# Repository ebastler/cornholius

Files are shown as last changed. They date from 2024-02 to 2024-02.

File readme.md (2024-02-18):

# Cornholius Keyboard

Cornholius is, first and foremost, a Bluetooth Low Energy capable replacement PCB for the [Foostan Cornelius](https://github.com/foostan/corneliuskbd). Key and connector positions as well as PCB outline and plate were derived from the original Cornelius repository, but altered to fit the scope of this project - Thank you for open sourcing these files! In accordance with the license chosen by foostan, this project was published under the same license: <a href="http://creativecommons.org/licenses/by-nc-sa/4.0/?ref=chooser-v1" target="_blank" rel="license noopener noreferrer" style="display:inline-block;">CC BY-NC-SA 4.0</a>.

Parts of this project:
* [PCB](./hotswap_ble/) [100%]
* [Plate](./plate_ble/) [100%]
* 3D printable cornelius/cornholius PCB compatible case [WIP]

## Cornholius PCB
The PCB is designed to be 100% assemblable by jlcpcb in their "economic" PCBA option (without hotswap sockets), or the more expensive "standard" PCBA option incl. hotswap sockets. It uses an [Ebyte nRF52840_E73-2G4M08S1C](https://www.ebyte.com/en/downpdf.aspx?id=445) BLE module, which is part of their component library, so no external components must be ordered from other shops. This module is configured for full 2-stage DC-DC operation in high voltage mode for maximum battery life.

Battery management is handled by a [TI BQ24075](http://www.ti.com/lit/ds/symlink/bq24075.pdf) battery management/power path IC, with a charge current of approx. 440 mA and all relevant protections in place. The PCB is designed for a HAC-006 (Nintendo Switch Joycon) battery, as replacement cells for it are affordable and easy to source, and are plug and play for Cornholius, incl. the right connector. It should lead to an estimated battery life of up to 8 months (according to ZMK power profiler).

If you want to use any other battery type, make sure it has a Molex Pico EZmate 2-pin connector, and the correct polarity. Connecting a battery with mismatched polarity may damage the PCB and can potentially turn into a fire hazard.

The 6th column on the PCB can be snapped off, turning it into a 5col PCB.

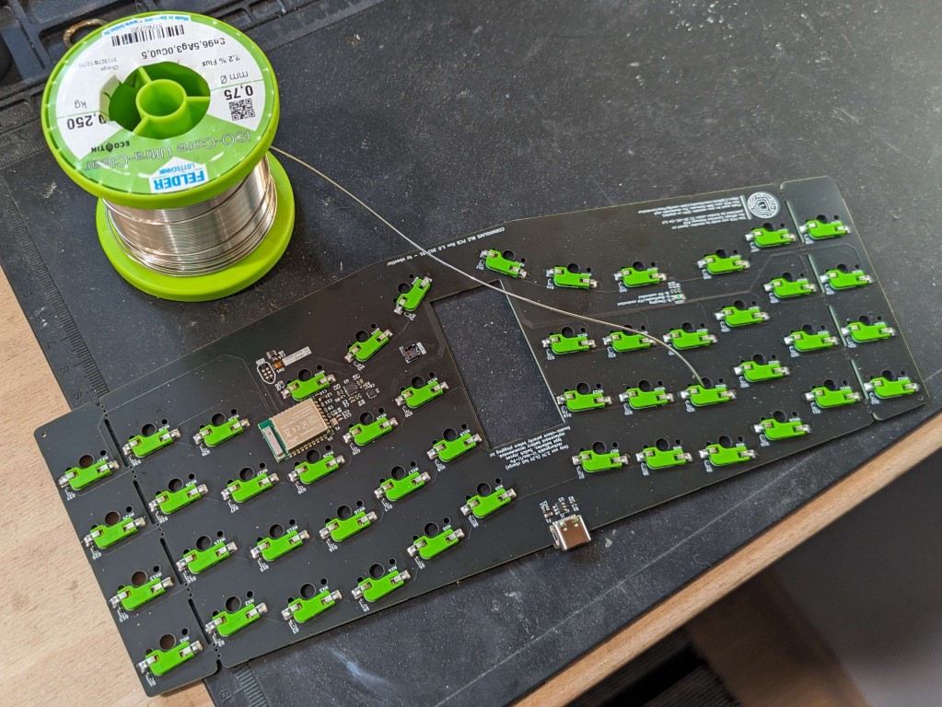
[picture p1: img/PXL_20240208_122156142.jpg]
soldering sockets

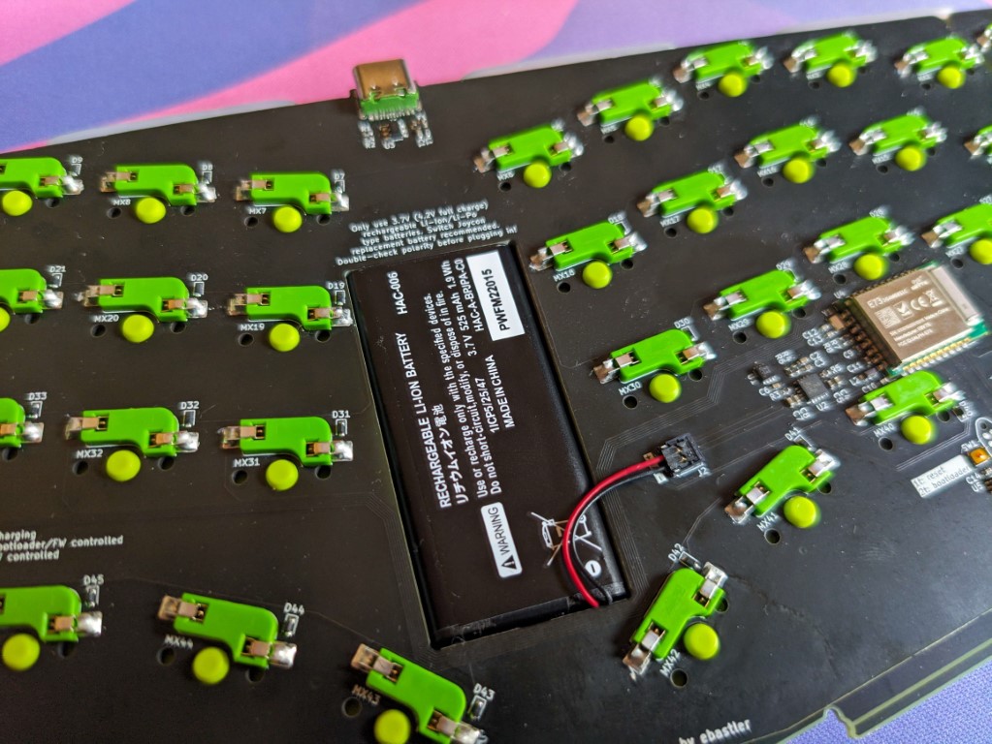
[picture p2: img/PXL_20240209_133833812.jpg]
battery closeup


### Programming
Flashing an nRF52840 forn the first time requires hardware tools. Joric wrote up a very good guide on how to program nRF52 series chips in the [nrfmicro github wiki](https://github.com/joric/nrfmicro/wiki/Bootloader). If you have never flashed a nRF52 series chip before, I suggest reading it before proceeding to order any hardware.

The PCB features a TC2030 flashing header footprint, configured in [TC2030-CTX-NL](https://www.tag-connect.com/wp-content/uploads/bsk-pdf-manager/TC2030-CTX_1.pdf) pinout. It should be possible to solder wires to this footprint and connect to a debug probe, but I have not tried. 

Precompiled bootloader files can be found in the Github Actions tab of my [fork of the Adafruit nRF52 Bootloader](https://github.com/ebastler/Adafruit_nRF52_Bootloader/actions).

Once the PCBs have a bootloader, they can be programmed via a UF2 mass-storage-device bootloader. Double-tapping the reset button (or using keybinds, once ZMK is running) will send the device to bootloader. 

### Ordering
Gerber files and assembly files can be found in the [hotswap_ble/fab subfolder](./hotswap_ble/fab/). Use 1.6mm FR4 substrate.

The jlcpcb assembly files are tested and were working at the time when I ordered prototypes, however, jlcpcb sometimes changes part numbers, or parts run out of stock and need to be replaced by new parts. Please proceed with caution and carefully check both BOM and position/alignment/orientation of all components when uploading to their site.

## Cornholius Plate
The plate is made from FR4 substrate, without any copper plating, to minimie interference with the antenna. It also has a hole above the PCB's status LED to keep it visible. While it is compatible with Cornelius cases, the outline and the gasket tabs were slightly altered from the original Cornelius plate to allow for o-ring mount in Cornholius.

### Ordering
Gerber files and assembly files can be found in the [plate_ble/fab subfolder](./plate_ble/fab/). Use 1.6mm FR4 substrate.

## Cornholius Case
tbd

This case will be designed to fit Cornholius and Cornelius PCBs, but only work with Cornholius plates due to the mounting design. While it will follow the Cornelius shape out of necessity, I want to give it a distinct design, setting it apart from the original. This section will be updated once the design is finalized.

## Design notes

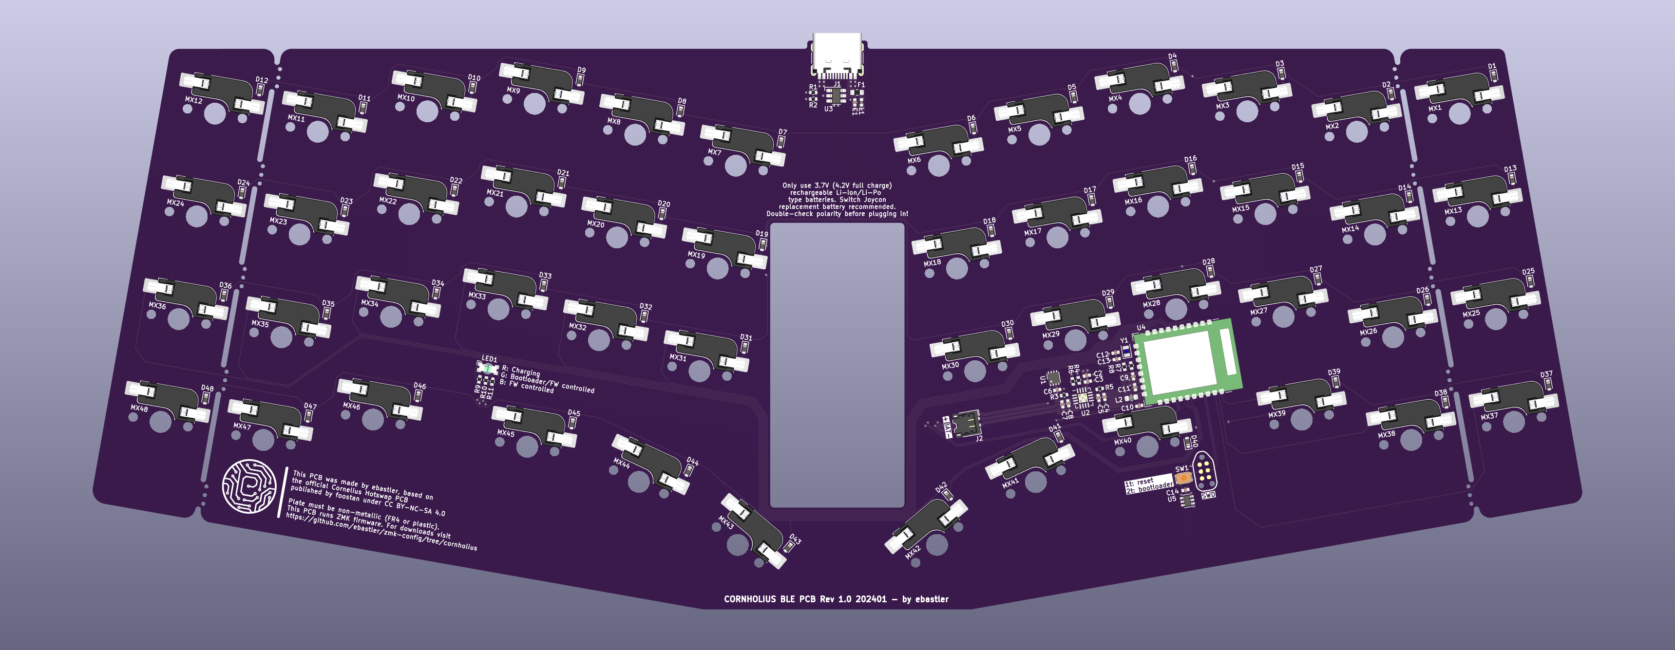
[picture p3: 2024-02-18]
hotswap_ble/fab/hotswap_ble-.bottom.png

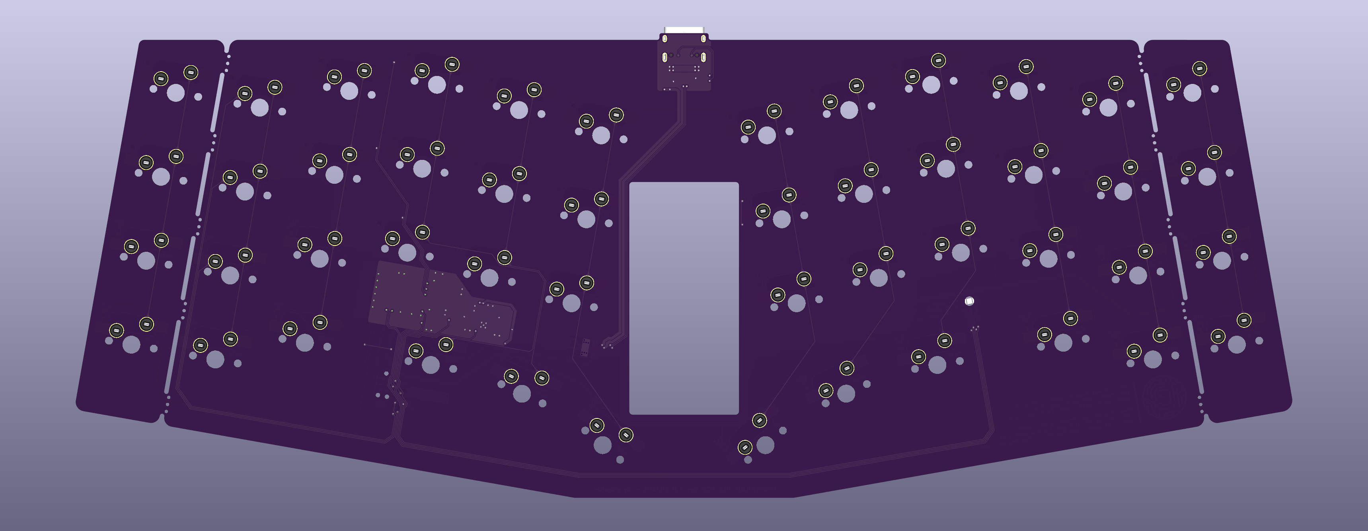
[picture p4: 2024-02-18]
hotswap_ble/fab/hotswap_ble-.top.png

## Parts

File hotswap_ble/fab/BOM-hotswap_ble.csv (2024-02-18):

Comment | Designator | Footprint | LCSC
RST | SW1 | SW_T1A2QR | C100056
1k | R10,R11,R9 | R_0402_1005Metric | C11702
BQ24075 | U2 | VQFN-16-1EP_3x3mm_P0.5mm_EP1.6x1.6mm | C15464
12p | C12,C13 | C_0402_1005Metric | C1547
TYPE-C-31-M-12 | J1 | USB_C_Receptacle_HRO_TYPE-C-31-M-12 | C165948
4u7 | C1,C10,C11,C2,C4,C7 | C_0402_1005Metric | C23733
10k | R3,R7,R8 | R_0402_1005Metric | C25744
47k | R4 | R_0402_1005Metric | C25792
1k5 | R5 | R_0402_1005Metric | C25867
2k2 | R6 | R_0402_1005Metric | C25879
5k1 | R1,R2 | R_0402_1005Metric | C25905
MAX17048 | U1 | DFN-8-1EP_2x2mm_P0.5mm_EP0.7x1.3mm | C2682616
IND | LED1 | LED_1206R | C2802677
100n | C14,C6 | C_0402_1005Metric | C307331
nRF52840_E73-2G4M08S1C | U4 | nRF52840_E73-2G4M08S1C | C356849
74LVC1G11 | U5 | SOT-363_SC-70-6 | C460525
78171-0002 | J2 | Molex_Pico-EZmate_78171-0002_1x02-1MP_P1.20mm_Vertical | C505023
MX | MX1,MX10,MX11,MX12,MX13,MX14,MX15,MX16,MX17,MX18,MX19,MX2,MX20,MX21,MX22,MX23,MX24,MX25,MX26,MX27,MX28,MX29,MX3,MX30,MX31,MX32,MX33,MX34,MX35,MX36,MX37,MX38,MX39,MX4,MX40,MX41,MX42,MX43,MX44,MX45,MX46,MX47,MX48,MX5,MX6,MX7,MX8,MX9 | SW_MX_HS_1u | C5184526
1u | C3,C5,C8,C9 | C_0402_1005Metric | C52923
32.768 KHz | Y1 | Crystal_SMD_2012-2Pin_2.0x1.2mm | C55208
1N4148WT | D1,D10,D11,D12,D13,D14,D15,D16,D17,D18,D19,D2,D20,D21,D22,D23,D24,D25,D26,D27,D28,D29,D3,D30,D31,D32,D33,D34,D35,D36,D37,D38,D39,D4,D40,D41,D42,D43,D44,D45,D46,D47,D48,D5,D6,D7,D8,D9 | D_SOD-523 | C727112
SRV05-4 | U3 | SOT-23-6-routable | C7420376
500mA | F1 | Fuse_0603_1608Metric | C883095
BLM15PX121SN1D | L1 | L_0402_1005Metric | C88970
10 uH | L2 | L_0603_1608Metric | C92982

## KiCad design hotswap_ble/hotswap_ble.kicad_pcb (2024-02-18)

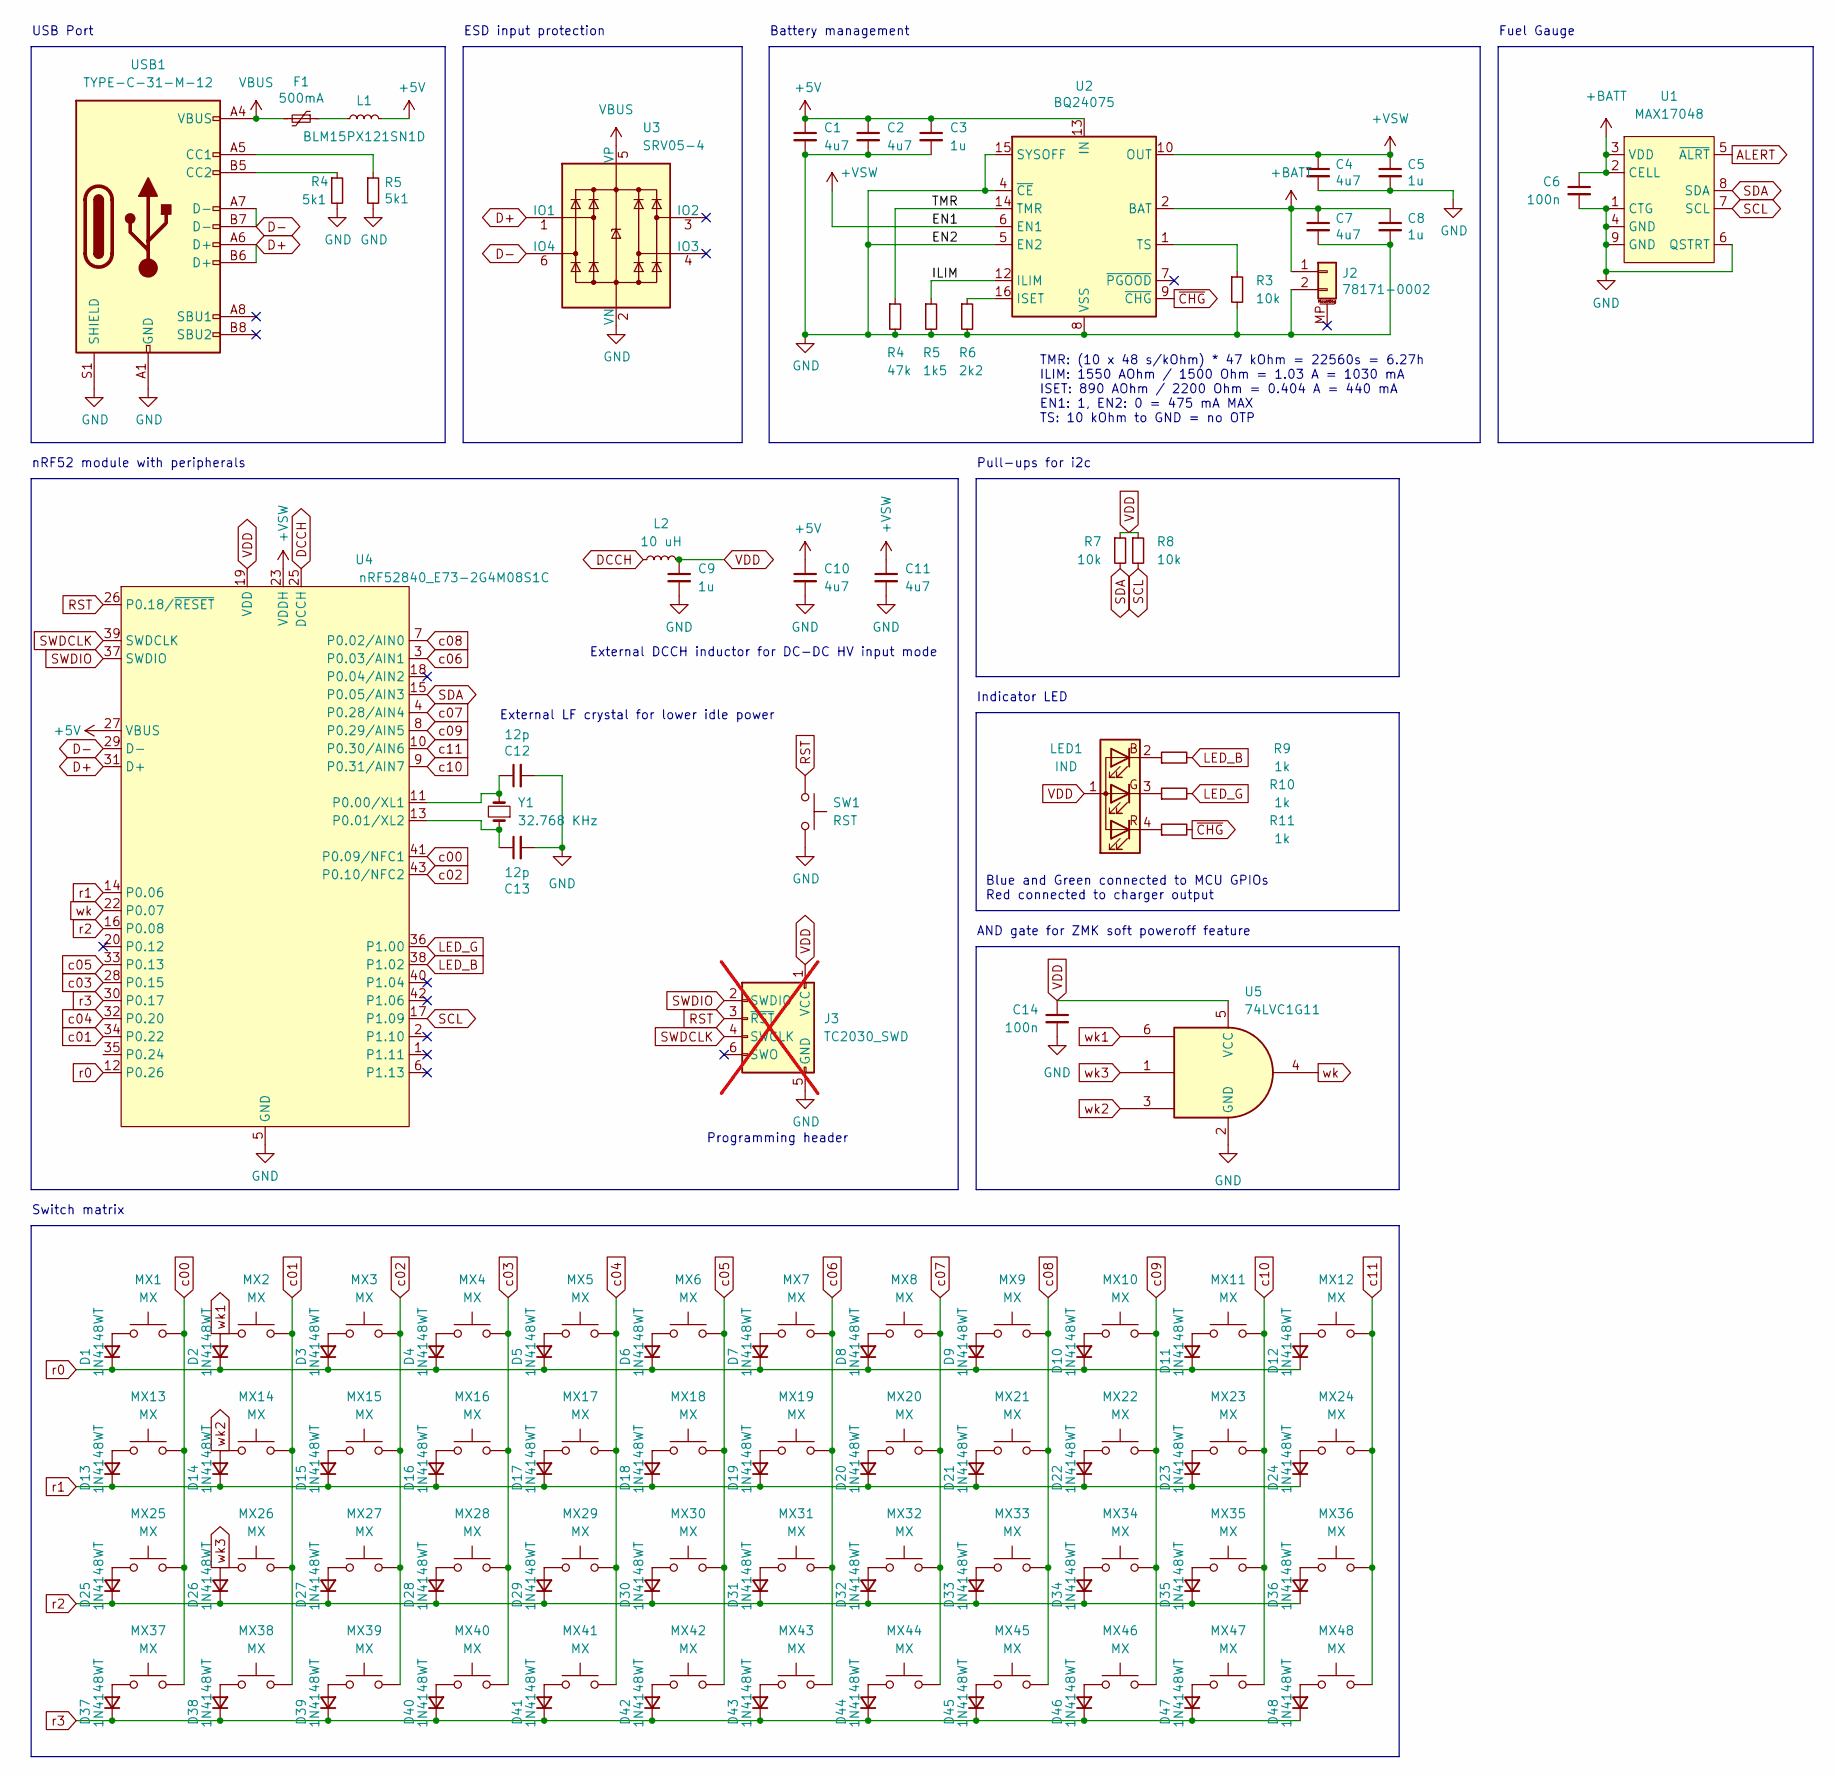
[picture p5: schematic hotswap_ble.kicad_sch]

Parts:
C1, C2, C4, C7, C10, C11: 4u7; C_0402_1005Metric; LCSC C23733
C3, C5, C8, C9: 1u; C_0402_1005Metric; LCSC C52923
C6, C14: 100n; C_0402_1005Metric; LCSC C307331
C12, C13: 12p; C_0402_1005Metric; LCSC C1547
D1, D2, D3, D4, D5, D6, D7, D8, D9, D10, D11, D12, D13, D14, D15, D16, D17, D18, D19, D20, D21, D22, D23, D24, D25, D26, D27, D28, D29, D30, D31, D32, D33, D34, D35, D36, D37, D38, D39, D40, D41, D42, D43, D44, D45, D46, D47, D48: 1N4148WT; D_SOD-523; LCSC C727112
F1: 500mA; Fuse_0603_1608Metric; LCSC C883095
J2: 78171-0002; Molex_Pico-EZmate_78171-0002_1x02-1MP_P1.20mm_Vertical; LCSC C505023
J3: TC2030_SWD; CON_TC2030_outlined; not fitted
L1: BLM15PX121SN1D; L_0402_1005Metric; LCSC C88970
L2: 10 uH; L_0603_1608Metric; LCSC C92982
LED1: IND; LED_1206R; LCSC C2802677
MX1, MX2, MX3, MX4, MX5, MX6, MX7, MX8, MX9, MX10, MX11, MX12, MX13, MX14, MX15, MX16, MX17, MX18, MX19, MX20, MX21, MX22, MX23, MX24, MX25, MX26, MX27, MX28, MX29, MX30, MX31, MX32, MX33, MX34, MX35, MX36, MX37, MX38, MX39, MX40, MX41, MX42, MX43, MX44, MX45, MX46, MX47, MX48: MX; SW_MX_HS_1u; LCSC C5184526
R3, R7, R8: 10k; R_0402_1005Metric; LCSC C25744
R4: 47k; R_0402_1005Metric; LCSC C25792
R5: 5k1; R_0402_1005Metric; LCSC C25905
R6: 2k2; R_0402_1005Metric; LCSC C25879
R9, R10, R11: 1k; R_0402_1005Metric; LCSC C11702
SW1: RST; SW_T1A2QR; LCSC C100056
U1: MAX17048; DFN-8-1EP_2x2mm_P0.5mm_EP0.7x1.3mm; LCSC C2682616
U2: BQ24075; VQFN-16-1EP_3x3mm_P0.5mm_EP1.6x1.6mm; LCSC C15464
U3: SRV05-4; SOT-23-6-routable; LCSC C7420376
U4: nRF52840_E73-2G4M08S1C; LCSC C356849
U5: 74LVC1G11; SOT-363_SC-70-6
USB1: TYPE-C-31-M-12; USB_C_Receptacle_HRO_TYPE-C-31-M-12; LCSC C165948
Y1: 32.768 KHz; Crystal_SMD_2012-2Pin_2.0x1.2mm; LCSC C55208

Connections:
+5V: C1.1, C2.1, C3.1, C10.1, L1.2, U2.13 (IN), U4.27 (VBUS)
+BATT: C6.1, C7.1, C8.1, J2.1, U1.2 (CELL), U1.3 (VDD), U2.2 (BAT), U2.3 (BAT)
+VSW: C4.1, C5.1, C11.1, U2.6 (EN1), U2.10 (OUT), U2.11 (OUT), U4.23 (VDDH)
ALERT: U1.5 (~ALRT)
D+: U3.1 (IO1), U4.31 (D+); also elsewhere on the board
D-: U3.6 (IO4), U4.29 (D-); also elsewhere on the board
DCCH: L2.1, U4.25 (DCCH)
GND: C1.2, C2.2, C3.2, C4.2, C5.2, C6.2, C7.2, C8.2, C9.2, C10.2, C11.2, C12.2, C13.2, C14.2, J2.2, J3.5 (GND), R3.2, R4.2, R5.2, R6.2, SW1.2, U1.1 (CTG), U1.4 (GND), U1.6 (QSTRT), U1.9 (GND), U2.4 (~CE), U2.5 (EN2), U2.8 (VSS), U2.15 (SYSOFF), U2.17 (VSS), U3.2 (VN), U4.5 (GND), U4.21 (GND), U4.24 (GND), U5.2 (GND); also elsewhere on the board
LED_B: R9.2, U4.38 (P1.02)
LED_G: R10.2, U4.36 (P1.00)
unnamed: D1.2 (A), MX1.1
unnamed: D3.2 (A), MX3.1
unnamed: D4.2 (A), MX4.1
unnamed: D5.2 (A), MX5.1
unnamed: D6.2 (A), MX6.1
unnamed: D7.2 (A), MX7.1
unnamed: D8.2 (A), MX8.1
unnamed: D9.2 (A), MX9.1
unnamed: D10.2 (A), MX10.1
unnamed: D11.2 (A), MX11.1
unnamed: D12.2 (A), MX12.1
unnamed: D13.2 (A), MX13.1
unnamed: D15.2 (A), MX15.1
unnamed: D16.2 (A), MX16.1
unnamed: D17.2 (A), MX17.1
unnamed: D18.2 (A), MX18.1
unnamed: D19.2 (A), MX19.1
unnamed: D20.2 (A), MX20.1
unnamed: D21.2 (A), MX21.1
unnamed: D22.2 (A), MX22.1
unnamed: D23.2 (A), MX23.1
unnamed: D24.2 (A), MX24.1
unnamed: D25.2 (A), MX25.1
unnamed: D27.2 (A), MX27.1
unnamed: D28.2 (A), MX28.1
unnamed: D29.2 (A), MX29.1
unnamed: D30.2 (A), MX30.1
unnamed: D31.2 (A), MX31.1
unnamed: D32.2 (A), MX32.1
unnamed: D33.2 (A), MX33.1
unnamed: D34.2 (A), MX34.1
unnamed: D35.2 (A), MX35.1
unnamed: D36.2 (A), MX36.1
unnamed: D37.2 (A), MX37.1
unnamed: D38.2 (A), MX38.1
unnamed: D39.2 (A), MX39.1
unnamed: D40.2 (A), MX40.1
unnamed: D41.2 (A), MX41.1
unnamed: D42.2 (A), MX42.1
unnamed: D43.2 (A), MX43.1
unnamed: D44.2 (A), MX44.1
unnamed: D45.2 (A), MX45.1
unnamed: D46.2 (A), MX46.1
unnamed: D47.2 (A), MX47.1
unnamed: D48.2 (A), MX48.1
unnamed: F1.1, L1.1
unnamed: LED1.2 (BK), R9.1
unnamed: LED1.3 (GK), R10.1
unnamed: LED1.4 (RK), R11.1
unnamed: R6.1, U2.16 (ISET)
unnamed: R3.1, U2.1 (TS)
unnamed: C12.1, U4.11 (P0.00/XL1), Y1.2
unnamed: C13.1, U4.13 (P0.01/XL2), Y1.1
RST: J3.3 (~RST), SW1.1, U4.26 (P0.18/~RESET)
SCL: R8.2, U1.7 (SCL), U4.17 (P1.09)
SDA: R7.2, U1.8 (SDA), U4.15 (P0.05/AIN3)
SWDCLK: J3.4 (SWCLK), U4.39 (SWDCLK)
SWDIO: J3.2 (SWDIO), U4.37 (SWDIO)
VBUS: F1.2, U3.5 (VP); also elsewhere on the board
VDD: C9.1, C14.1, J3.1 (VCC), L2.2, LED1.1 (A), R7.1, R8.1, U4.19 (VDD), U5.5 (VCC)
c00: MX1.2, MX13.2, MX25.2, MX37.2, U4.41 (P0.09/NFC1)
c01: MX2.2, MX14.2, MX26.2, MX38.2, U4.34 (P0.22)
c02: MX3.2, MX15.2, MX27.2, MX39.2, U4.43 (P0.10/NFC2)
c03: MX4.2, MX16.2, MX28.2, MX40.2, U4.28 (P0.15)
c04: MX5.2, MX17.2, MX29.2, MX41.2, U4.32 (P0.20)
c05: MX6.2, MX18.2, MX30.2, MX42.2, U4.33 (P0.13)
c06: MX7.2, MX19.2, MX31.2, MX43.2, U4.3 (P0.03/AIN1)
c07: MX8.2, MX20.2, MX32.2, MX44.2, U4.4 (P0.28/AIN4)
c08: MX9.2, MX21.2, MX33.2, MX45.2, U4.7 (P0.02/AIN0)
c09: MX10.2, MX22.2, MX34.2, MX46.2, U4.8 (P0.29/AIN5)
c10: MX11.2, MX23.2, MX35.2, MX47.2, U4.9 (P0.31/AIN7)
c11: MX12.2, MX24.2, MX36.2, MX48.2, U4.10 (P0.30/AIN6)
r0: D1.1 (K), D2.1 (K), D3.1 (K), D4.1 (K), D5.1 (K), D6.1 (K), D7.1 (K), D8.1 (K), D9.1 (K), D10.1 (K), D11.1 (K), D12.1 (K), U4.12 (P0.26)
r1: D13.1 (K), D14.1 (K), D15.1 (K), D16.1 (K), D17.1 (K), D18.1 (K), D19.1 (K), D20.1 (K), D21.1 (K), D22.1 (K), D23.1 (K), D24.1 (K), U4.14 (P0.06)
r2: D25.1 (K), D26.1 (K), D27.1 (K), D28.1 (K), D29.1 (K), D30.1 (K), D31.1 (K), D32.1 (K), D33.1 (K), D34.1 (K), D35.1 (K), D36.1 (K), U4.16 (P0.08)
r3: D37.1 (K), D38.1 (K), D39.1 (K), D40.1 (K), D41.1 (K), D42.1 (K), D43.1 (K), D44.1 (K), D45.1 (K), D46.1 (K), D47.1 (K), D48.1 (K), U4.30 (P0.17)
wk: U4.22 (P0.07), U5.4
wk1: D2.2 (A), MX2.1, U5.6
wk2: D14.2 (A), MX14.1, U5.3
wk3: D26.2 (A), MX26.1, U5.1
~CHG: R11.2, U2.9 (~CHG)

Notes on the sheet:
nRF52 module with peripherals
Fuel Gauge
Indicator LED
AND gate for ZMK soft poweroff feature
Programming header
External LF crystal for lower idle power
USB Port
ESD input protection
TMR: (10 x 48 s/kOhm) * 47 kOhm = 22560s = 6.27h ILIM: 1550 AOhm / 1500 Ohm = 1.03 A = 1030 mA ISET: 890 AOhm / 2200 Ohm = 0.404 A = 440 mA EN1: 1, EN2: 0 = 475 mA MAX TS: 10 kOhm to GND = no OTP
External DCCH inductor for DC-DC HV input mode
Pull-ups for i2c
Battery management
Switch matrix
Blue and Green connected to MCU GPIOs Red connected to charger output

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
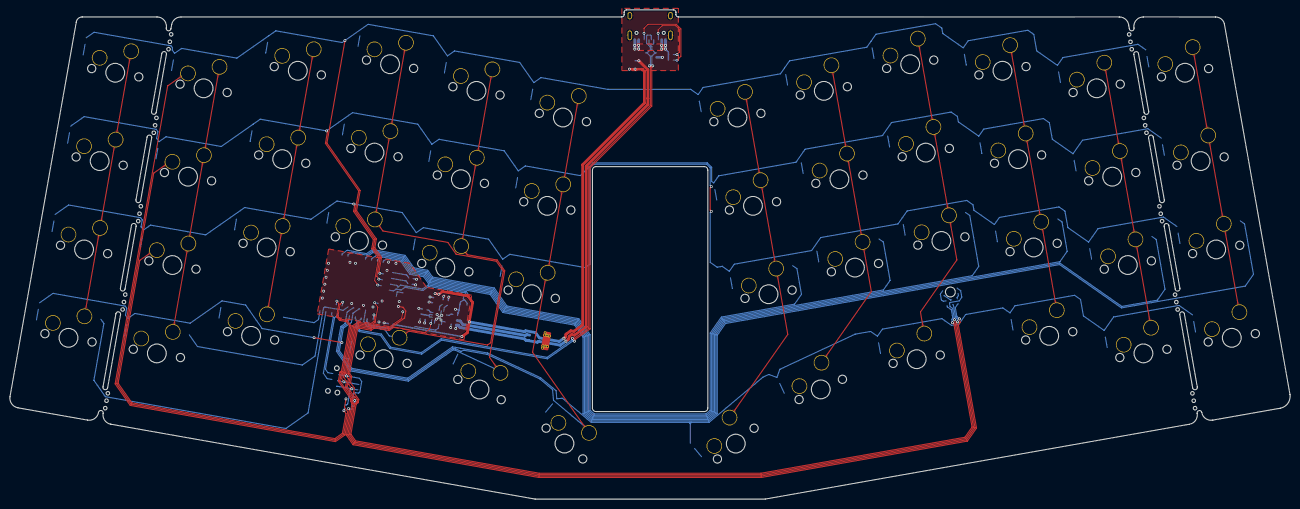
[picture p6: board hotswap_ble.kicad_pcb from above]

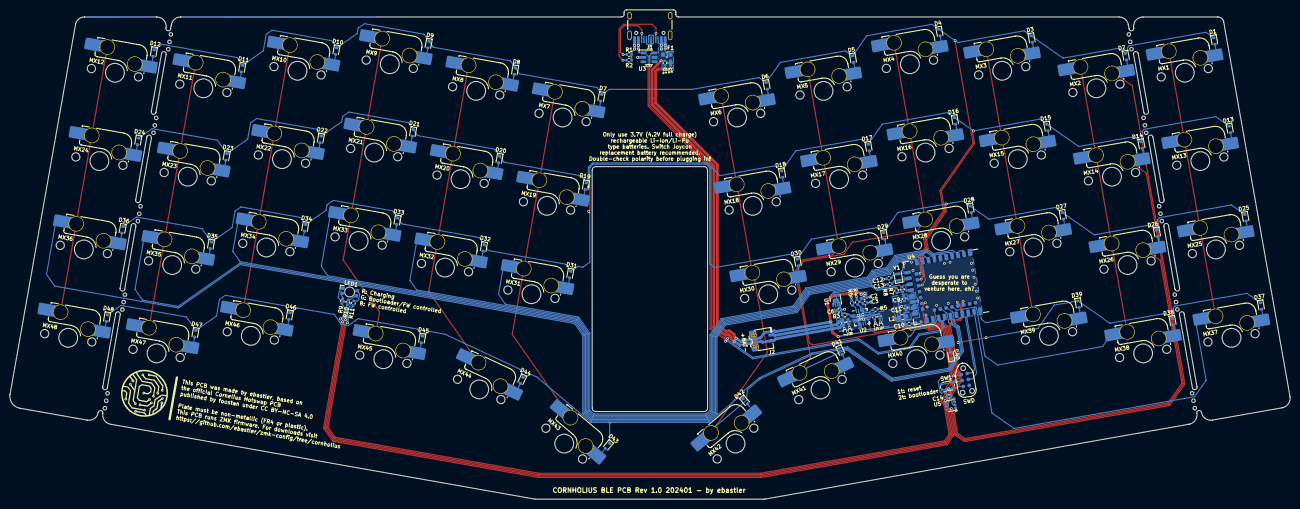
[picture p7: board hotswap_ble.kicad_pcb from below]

Board: 2 copper layers, 271.8 x 103.9 mm, 135 parts (135 on the bottom side), 94 nets.

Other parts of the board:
J1: TYPE-C-31-M-12; USB_C_Receptacle_HRO_TYPE-C-31-M-12
R1, R2: 5k1; R_0402_1005Metric

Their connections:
D+: J1.A6 (D+), J1.B6 (D+); also elsewhere on the board
D-: J1.A7 (D-), J1.B7 (D-); also elsewhere on the board
GND: J1.A1 (GND), J1.A12 (GND), J1.B1 (GND), J1.B12 (GND), J1.S1 (SHIELD), R1.2, R2.2; also elsewhere on the board
VBUS: J1.A4 (VBUS), J1.A9 (VBUS), J1.B4 (VBUS), J1.B9 (VBUS); also elsewhere on the board

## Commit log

2024-02-18 add gitignore for kicad projects
2024-02-18 add pcb and plate files
    [BOM-hotswap_ble.csv, hotswap_ble.kicad_pcb, hotswap_ble.kicad_sch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]
2026-01-05 Update readme.md
    Add links and info regarding 3d printed case

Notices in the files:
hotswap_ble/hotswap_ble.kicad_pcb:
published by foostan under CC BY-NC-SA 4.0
